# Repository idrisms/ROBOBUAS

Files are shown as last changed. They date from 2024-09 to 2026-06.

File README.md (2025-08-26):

## Demo Video untuk buyo menggunakan apps android

Tonton Video (https://youtube.com/shorts/SF0n9ZDPM6c?si=8_inQVv74NJLRzca)

ROBOBUAS

Bagai mana nak mula

1 - Muat turun semua kod dalam satu folder untuk sumo auto, untuk RC guna kod dalam MOTOR_ESP32HOTRC_V01
2 - Install Arduino software kalau belum (https://www.arduino.cc/en/software)
- 

3 - Install board manager ESP32 dari Espressif
Buka perisian arduino, kemudian tekan Board manager

Kemudian pilih kawasan carian dan cari esp32


4 - Lnstall CH341 untuk microcontroller esp32 kalau belum (https://www.wch-ic.com/downloads/CH341SER_ZIP.html)
- 

5- Extract dan click setup
- 

6 - Install CH341SER dengan menekan butang "INSTALL"
- 

7 - Bagaimana nak muat naik code. Tekan >> Tools >> Esp32 >> ESP32-WROOM-DA Module
7 - Bagaimana nak muat naik code. Tekan >> Tools >> Board >> ESP32-WROOM-DA Module
- 

8 - Sambungkan arduino anda dan pilih port yang telah aktif. Akan ade bunyi sesuatu di PC/Laptop anda sekiranya ESp32-30 di pasangkan sudah di kesan. Tekan Tools >> PORT >> Nombor port anda


9 - pastikan pilihan board dan port ayng betul
- 

10 - Waktu Muat Naik code di dalam ESP32,kadang-kadang perlu tekan butang Boot pada ESP32 waktu connecting keluar titik-titik......
- 
- 

**Untuk RC**
- Download MOTOR_ESP32HOTRC_V01 dan upload ke dalam robobuas esp32 board 
- Ikut seperti pendawaian di dalam https://sites.google.com/view/robobuasbuyov1
- JIka Board anda bukan ROBOBUAS BUYO, sila tukar nombor bin dalam kod berdasarkan nombor pin anda.
- 

- Hidupkan RC controller
- "BIND" receiver dengan transmitter bergantung kepada jenis RC controller anda
- Hidupkan Robot setelah semua pendawaian telah di semak. sebarang kerosakan board tidak ditanggung sekiranya semakan tidak di buat terlebih dahulu.**Pastikan RCcontroller tidak ditekan**
- Robot akan bergerak sendiri di awal suis dihidupkan selama beberapa saat namun ia akan berhenti sendiri sekiranyaia telah tersambung ke RC Controller
- Biasanya lampu receiver akan menyala tanpa berkelip sekiranya telah bersambung dengan RC controller
- Jika robot telah tersambung kepada controller, tetapi masih ada bunyi atau pergerakan yang perlahan, tinggikan nilai "OFFSET" secara gandaan 10 dan muat naik kod yang telah diubah
- 

- **AMARAN- Sila cabut ESP32 daripada ROBOBUAS untuk muat naikkod kerana board akan menyalurkan kuasa dari kabel USB ke Motor dan boleh merosakkan PC/LAPTOP sekiranya dibiarkan untuk tempoh yang lama**
- Tambah nilai offset sehinga tiada pergerakan walaupun RC controller tidak ditekan
- Sekirannya gerakan terbalik,tukar wayar dc motor kepada wayar pasangannya
- Sekiranya semua langkah-langkah ini diikuti dengan teliti, InsyaALLAH robot akan berfungsi

**UNtuk Auto**
- Buka SUMOROBOTAUTO_ROBOBUAS.ino menggunakan perisian ARDUINO
- Cara-cara ubah tetapan ada di dalam itu.

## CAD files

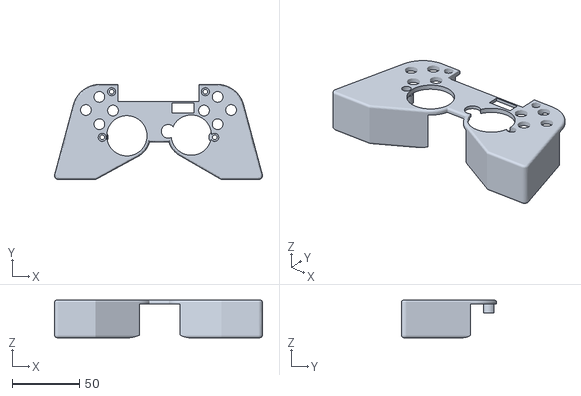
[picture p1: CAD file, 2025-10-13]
BEDIK/topcover_bedik.stl
155.0 x 70.9 x 28.0

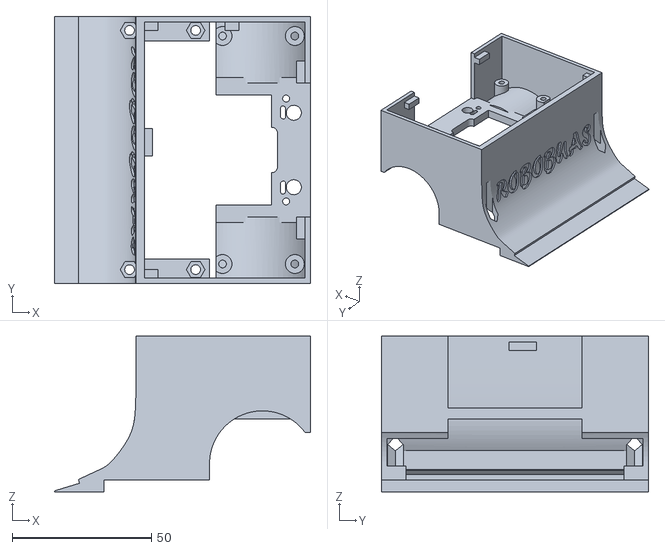
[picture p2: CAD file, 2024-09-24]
STL500RC/frontv2.stl
92.1 x 96.0 x 56.0

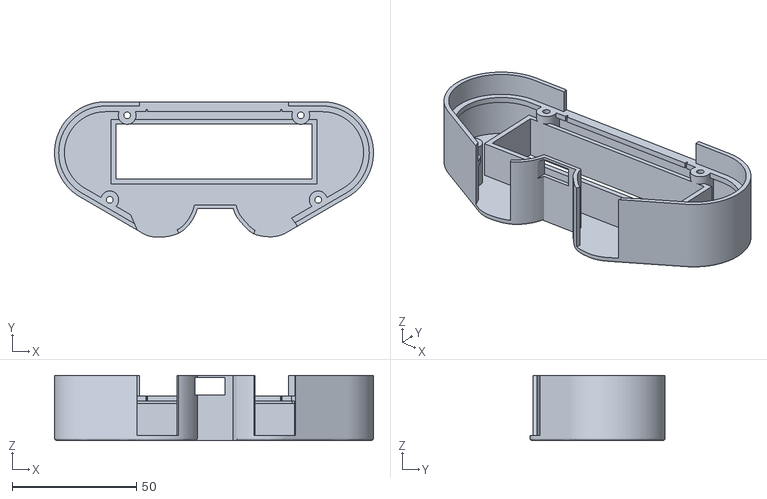
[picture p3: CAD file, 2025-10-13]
BEDIK/botcov_bedik.stl
128.4 x 54.5 x 26.2

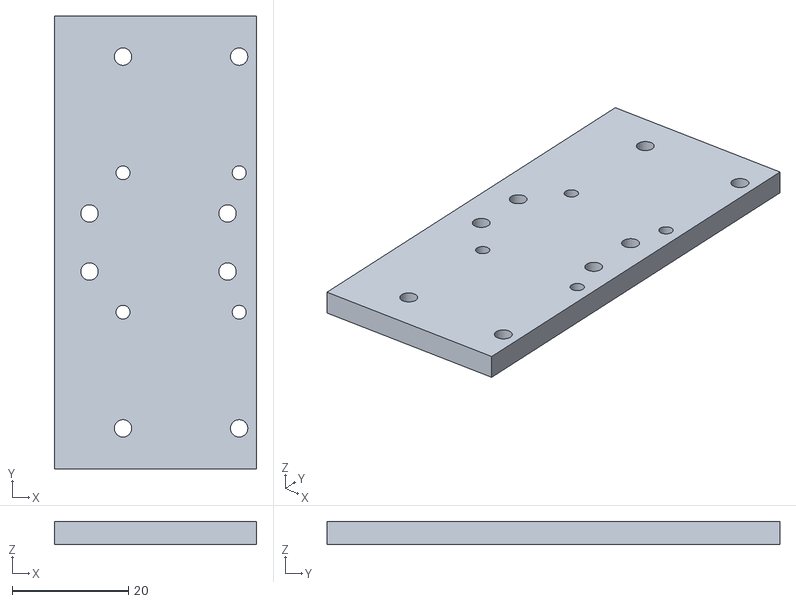
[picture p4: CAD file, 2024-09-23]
STL500RC/weigher.stl
34.8 x 78.0 x 4.00

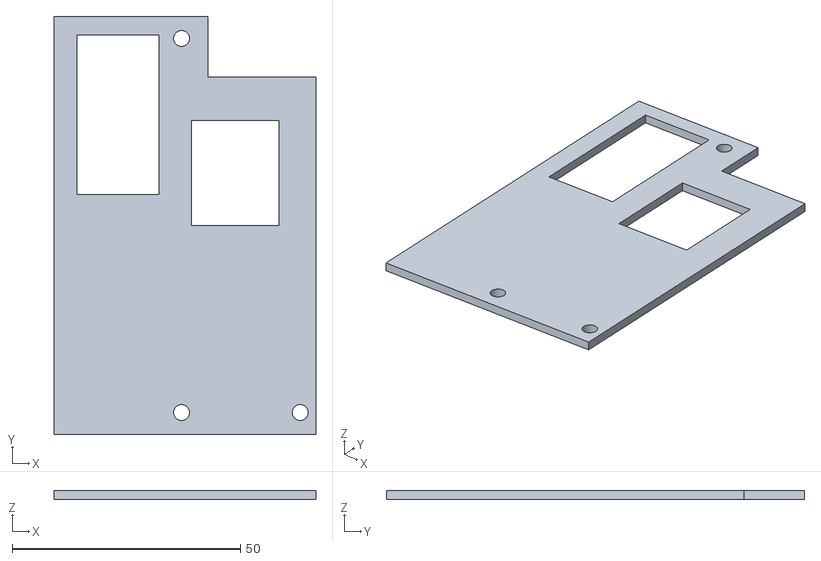
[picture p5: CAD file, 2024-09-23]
STL500RC/cover.stl
57.4 x 91.6 x 2.00

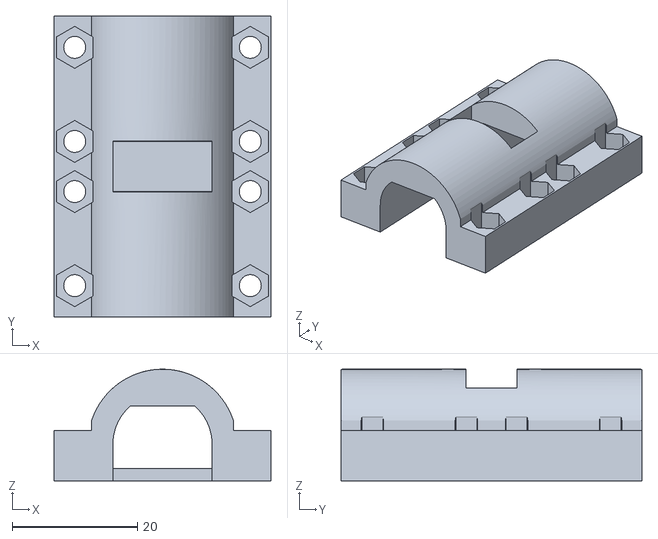
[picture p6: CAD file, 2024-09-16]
STL500RC/motorholder.stl
34.6 x 48.0 x 17.8

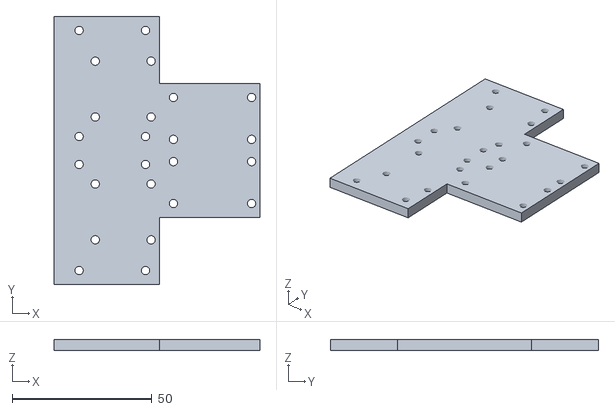
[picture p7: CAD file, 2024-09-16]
STL500RC/base.stl
73.8 x 96.0 x 4.00

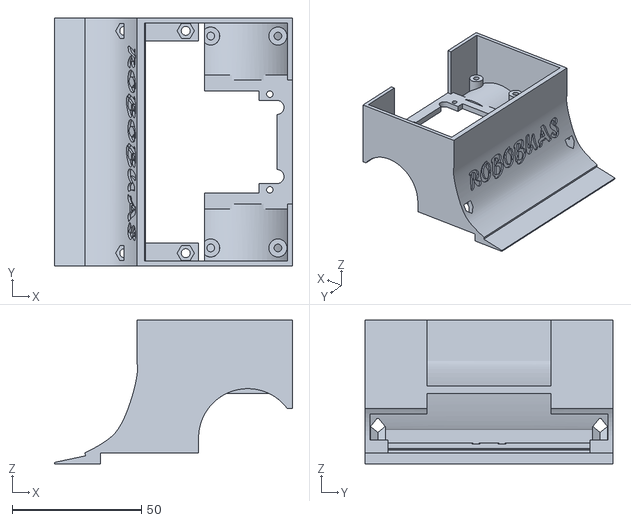
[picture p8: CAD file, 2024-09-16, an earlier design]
STL500RC/front(old).stl
92.1 x 96.0 x 55.6

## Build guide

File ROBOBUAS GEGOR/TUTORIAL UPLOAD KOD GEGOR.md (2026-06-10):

ROBOBUAS GEGOR

Bagai mana nak mula

1 - Muat turun kod RC_GEGOR_V1_0_FULL_VOLTAGE_LOCK.ino https://github.com/idrisms/ROBOBUAS/blob/main/ROBOBUAS%20GEGOR/RC_GEGOR_V1_0_FULL_VOLTAGE_LOCK.ino

2 - Install Arduino software kalau belum (https://www.arduino.cc/en/software)
- 

3 - Install board manager ESP32 dari Espressif
Buka perisian arduino, kemudian tekan Board manager

Kemudian pilih kawasan carian dan cari esp32


4 - Lnstall CH341 untuk microcontroller esp32 kalau belum (https://www.wch-ic.com/downloads/CH341SER_ZIP.html)
- 

5- Extract dan click setup
- 

6 - Install CH341SER dengan menekan butang "INSTALL"
- 

7 - Bagaimana nak muat naik code. Tekan >> Tools >> Esp32 >> ESP32-WROOM-DA Module
 
- 

8 - Sambungkan arduino anda dan pilih port yang telah aktif. Akan ade bunyi sesuatu di PC/Laptop anda sekiranya ESp32-30 di pasangkan sudah di kesan. Tekan Tools >> PORT >> Nombor port anda


9 - pastikan pilihan board dan port yang betul
- 

10 - Jika nak gunakan battery lipo 2s atau tak mahunguna safety battery, sila tukar nilai VMIN = 9.9 kepada 6.6 untuk lipo 2s (7.4V) atau kepada 0.0 jika anda tak mau safety pada battery

11-Contoh cara nak install library. Tekan icon library, cari neopixel dan install library Neopixel yang dibulatkan.
579013854-72b96216-1686-4d35-9036-d260c8034658



12 - Install Semua library yang diperlukan







13 - Waktu Muat Naik code di dalam ESP32,kadang-kadang perlu tekan butang Boot pada ESP32 waktu connecting keluar titik-titik......
- 
- 

**Untuk RC**

- Hidupkan RC controller
- "BIND" receiver dengan transmitter bergantung kepada jenis RC controller anda
- Hidupkan Robot setelah semua pendawaian telah di semak. sebarang kerosakan board tidak ditanggung sekiranya semakan tidak di buat terlebih dahulu.**Pastikan RCcontroller tidak ditekan**
- Biasanya lampu receiver akan menyala tanpa berkelip sekiranya telah bersambung dengan RC controller
- Jika robot telah tersambung kepada controller, tetapi masih ada bunyi atau pergerakan yang perlahan, ejas setting dekat remote
- Sekiranya gerakan terbalik,tukar wayar dc motor kepada wayar pasangannya
- Sekiranya semua langkah-langkah ini diikuti dengan teliti, InsyaALLAH robot akan berfungsi

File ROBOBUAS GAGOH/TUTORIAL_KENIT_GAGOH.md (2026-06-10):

1 - Muat turun code kenit/gagoh

2 - Install Arduino software kalau belum (https://www.arduino.cc/en/software)
- 

3 - Install board manager RPI dan tambah link ini (  https://github.com/earlephilhower/arduino-pico/releases/download/4.0.2/package_rp2040_index.json  ) dalam FILE->preferences
  

4 - Buka perisian arduino, kemudian tekan Board manager
  
  
5 - Kemudian pilih kawasan carian dan cari pico dan pilih seperti anak panah dan click install
  

6 - Sambung pendawaian seperti dalam https://sites.google.com/view/robobuasbuyopage/kenit

7 - Bagaimana nak muat naik code. Tekan >> Tools >> Board >> Raspberry Pi Pico >> Zero


8 - Install library Adafruit Neopixel jika guna code untuk Gagoh. Tekan icon library, cari neopixel dan install library enopixel yang dibulatkan
579013854-72b96216-1686-4d35-9036-d260c8034658

9 - Pilih port setelah di laptop/pc kenalpasti board dan muat naik seperti biasa

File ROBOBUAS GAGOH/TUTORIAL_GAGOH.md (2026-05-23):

1 - Muat turun code RC GAGGOH V2.2 (RC_GAGGOH_V2_2neo.ino untuk yang ada battery 12V safety-below 10V), (RC_GAGGOH_V2_2neo_noSafetyBat.ino untuk yang takde safety battery)

2 - Install Arduino software kalau belum (https://www.arduino.cc/en/software)
- 

3 - Install board manager RPI dan tambah link ini (  https://github.com/earlephilhower/arduino-pico/releases/download/4.0.2/package_rp2040_index.json  ) dalam FILE->preferences
  

4 - Buka perisian arduino, kemudian tekan Board manager
  
  
5 - Kemudian pilih kawasan carian dan cari pico dan pilih seperti anak panah dan click install
  

6 - Sambung pendawaian seperti dalam https://sites.google.com/view/robobuasbuyopage/kenit

7 - Bagaimana nak muat naik code. Tekan >> Tools >> Board >> Raspberry Pi Pico >> Zero


8 - Install library Adafruit Neopixel jika guna code untuk Gagoh. Tekan icon libreary, cari neopixel dan install library neopixel yang dibulatkan
579013854-72b96216-1686-4d35-9036-d260c8034658

9 - Pilih port setelah di laptop/pc kenalpasti board dan muat naik seperti biasa

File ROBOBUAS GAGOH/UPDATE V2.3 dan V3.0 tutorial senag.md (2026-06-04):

## Video Tutorial

Klik gambar di bawah untuk tonton video:

Tonton Video (https://youtube.com/shorts/C461Je05Bqs?si=8az38_ArpD2pnaIS)

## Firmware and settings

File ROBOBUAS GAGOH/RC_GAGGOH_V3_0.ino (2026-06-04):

/*
  =====================================================
  ROBOBUAS RC GAGOH V3.0
  -----------------------------------------------------
  Function:
  - RC control using CH1 and CH2
  - NeoPixel status LED
  - Forward and backward compensation using trimmer
  - Battery voltage check ONLY when robot is STOP
  - Low battery lock if Vbat <= Vmin
  - After lock, voltage can be checked again ONLY when STOP
  =====================================================
*/

#include <Adafruit_NeoPixel.h>

// ================= NEOPIXEL SETUP =================
#define PINSA 16
#define NUMPIXELS 1
Adafruit_NeoPixel pixels(NUMPIXELS, PINSA, NEO_GRB + NEO_KHZ800);

// ================= RC RECEIVER PIN =================
const int chA = 14;   // CH1 steering
const int chB = 15;   // CH2 throttle

// ================= MOTOR DRIVER PIN =================
#define M1B_PIN 4
#define M1A_PIN 7
#define EN_PIN 8
#define M2A_PIN 5
#define M2B_PIN 6

// ================= ANALOG INPUT PIN =================
#define VBAT_PIN 29
#define TRIMMER_PIN_FW 28
#define TRIMMER_PIN_BW 27

// ================= RC VARIABLE =================
int ch1, ch2;
int ch1prev = 1500;
int ch2prev = 1500;

int ch1Min = 1000;
int ch1Max = 2000;
int ch2Min = 1050;
int ch2Max = 1950;

int offset = 40;

// ================= BATTERY SETTING =================
float Vbat = 0;
const float pekali = 0.02992;

// Vmin = bilangan cell x 3.3V
// 2S LiPo = 6.6V
// 3S LiPo = 9.9V
// 4S LiPo = 13.2V
const float Vmin = 9.9;

// Unlock semula bila voltage naik lebih daripada Vmin + margin
const float recoveryMargin = 0.3;
const float maxBias =100;

bool lowBatteryLock = false;

// ================= COMPENSATION VARIABLE =================
int compensateRightFW = 0;
int compensateLeftFW = 0;
int compensateRightBW = 0;
int compensateLeftBW = 0;

// ================= LOW BATTERY BLINK =================
bool lowBatteryBlink = false;
unsigned long lastLowBatteryBlink = 0;
const unsigned long lowBatteryBlinkInterval = 200;

// ================= STOP MOTOR =================
void stopMotor() {
  analogWrite(M1A_PIN, 0);
  analogWrite(M1B_PIN, 0);
  analogWrite(M2A_PIN, 0);
  analogWrite(M2B_PIN, 0);
}

// ================= DRIVE MOTOR =================
// Semua arahan motor akan lalu function ini.
// Jika lowBatteryLock aktif, motor terus dipaksa STOP.
void driveMotor(int leftPWM, int rightPWM) {
  if (lowBatteryLock) {
    stopMotor();
    return;
  }

  leftPWM = constrain(leftPWM, -255, 255);
  rightPWM = constrain(rightPWM, -255, 255);

  // Left motor direction
  if (leftPWM > 0) {
    analogWrite(M1A_PIN, leftPWM);
    analogWrite(M1B_PIN, 0);
  } else if (leftPWM < 0) {
    analogWrite(M1A_PIN, 0);
    analogWrite(M1B_PIN, abs(leftPWM));
  } else {
    analogWrite(M1A_PIN, 0);
    analogWrite(M1B_PIN, 0);
  }

  // Right motor direction
  if (rightPWM > 0) {
    analogWrite(M2A_PIN, rightPWM);
    analogWrite(M2B_PIN, 0);
  } else if (rightPWM < 0) {
    analogWrite(M2A_PIN, 0);
    analogWrite(M2B_PIN, abs(rightPWM));
  } else {
    analogWrite(M2A_PIN, 0);
    analogWrite(M2B_PIN, 0);
  }
}

// ================= LOW BATTERY LED =================
void lowBatteryStop() {
  stopMotor();

  unsigned long now = millis();

  if (now - lastLowBatteryBlink >= lowBatteryBlinkInterval) {
    lowBatteryBlink = !lowBatteryBlink;
    lastLowBatteryBlink = now;
  }

  if (lowBatteryBlink) {
    pixels.setPixelColor(0, pixels.Color(80, 20, 0));  // orange blink
  } else {
    pixels.setPixelColor(0, pixels.Color(0, 0, 0));
  }

  pixels.show();
}

// ================= READ FORWARD TRIMMER =================
void readTrimmerFW() {
  int trimValueFW = analogRead(TRIMMER_PIN_FW);

  if (trimValueFW < 512) {
    compensateLeftFW = map(512 - trimValueFW, 0, 512, 0, maxBias);
    compensateRightFW = 0;
  } else {
    compensateRightFW = map(trimValueFW - 512, 0, 511, 0, maxBias);
    compensateLeftFW = 0;
  }
}

// ================= READ BACKWARD TRIMMER =================
void readTrimmerBW() {
  int trimValueBW = analogRead(TRIMMER_PIN_BW);

  if (trimValueBW < 512) {
    compensateLeftBW = map(512 - trimValueBW, 0, 512, 0, maxBias);
    compensateRightBW = 0;
  } else {
    compensateRightBW = map(trimValueBW - 512, 0, 511, 0, maxBias);
    compensateLeftBW = 0;
  }
}

// Negative value means compensation to left side.
// Positive value means compensation to right side.
int getCompFWDisplay() {
  if (compensateLeftFW > 0) return -compensateLeftFW;
  return compensateRightFW;
}

int getCompBWDisplay() {
  if (compensateLeftBW > 0) return -compensateLeftBW;
  return compensateRightBW;
}

void setup() {
  Serial.begin(115200);

  pinMode(chA, INPUT);
  pinMode(chB, INPUT);

  pinMode(M1A_PIN, OUTPUT);
  pinMode(M1B_PIN, OUTPUT);
  pinMode(M2A_PIN, OUTPUT);
  pinMode(M2B_PIN, OUTPUT);
  pinMode(EN_PIN, OUTPUT);

  digitalWrite(EN_PIN, HIGH);
  stopMotor();

  pixels.begin();

  // Startup LED test
  pixels.setPixelColor(0, pixels.Color(20, 0, 0));
  pixels.show();
  delay(300);

  pixels.setPixelColor(0, pixels.Color(0, 20, 0));
  pixels.show();
  delay(300);

  pixels.setPixelColor(0, pixels.Color(0, 0, 20));
  pixels.show();
  delay(300);

  pixels.clear();
  pixels.show();

  delay(500);
}

void loop() {
  // Read compensation trimmer
  readTrimmerFW();
  readTrimmerBW();

  // Read RC signal
  ch1 = pulseIn(chA, HIGH, 30000);
  delay(1);

  ch2 = pulseIn(chB, HIGH, 30000);
  delay(1);

  // If signal lost, use previous value
  if (ch1 < 700) ch1 = ch1prev;
  else ch1 = constrain(ch1, ch1Min, ch1Max);

  if (ch2 < 700) ch2 = ch2prev;
  else ch2 = constrain(ch2, ch2Min, ch2Max);

  ch1prev = ch1;
  ch2prev = ch2;

  // Convert RC signal to PWM value
  int SpeedCh1 = map(ch1, ch1Min, ch1Max, -255, 255);
  int SpeedCh2 = map(ch2, ch2Min, ch2Max, -255, 255);

  int forward = SpeedCh2;
  int turn = SpeedCh1;

  bool belowOffset = abs(forward) < offset && abs(turn) < offset;

  // Serial monitor display
  Serial.print("CH1:");
  Serial.print(ch1);
  Serial.print(" | CH2:");
  Serial.print(ch2);
  Serial.print(" | SPD1:");
  Serial.print(SpeedCh1);
  Serial.print(" | SPD2:");
  Serial.print(SpeedCh2);
  Serial.print(" | VBAT:");
  Serial.print(Vbat);
  Serial.print(" | LOCK:");
  Serial.print(lowBatteryLock);
  Serial.print(" | CompFW:");
  Serial.print(getCompFWDisplay());
  Serial.print(" | CompBW:");
  Serial.print(getCompBWDisplay());

  if (belowOffset) {
    Serial.print(" | Motion:STOP");
  } else if (lowBatteryLock) {
    Serial.print(" | Motion:LOW BAT");
  } else if (abs(forward) >= abs(turn)) {
    if (forward > 0) Serial.print(" | Motion:FW");
    else Serial.print(" | Motion:BW");
  } else {
    if (turn > 0) Serial.print(" | Motion:RIGHT");
    else Serial.print(" | Motion:LEFT");
  }

  // Voltage check hanya waktu STOP
  if (belowOffset) {
    stopMotor();

    Vbat = analogRead(VBAT_PIN) * pekali;

    if (Vbat <= Vmin) {
      lowBatteryLock = true;
    }

    if (lowBatteryLock && Vbat > (Vmin + recoveryMargin)) {
      lowBatteryLock = false;
    }

    if (lowBatteryLock) {
      lowBatteryStop();
      Serial.println(" | LOW BATTERY LOCK");
    } else {
      pixels.setPixelColor(0, pixels.Color(0, 30, 0));
      pixels.show();
      Serial.println(" | STOP / BATTERY OK");
    }

    delay(15);
    return;
  }

  // Kalau battery lock, motor tidak dibenarkan bergerak
  if (lowBatteryLock) {
    lowBatteryStop();
    Serial.println(" | LOW BATTERY MOTOR BLOCKED");
    delay(15);
    return;
  }

  // Normal movement LED
  if (forward > 0) {
    pixels.setPixelColor(0, pixels.Color(0, 0, 30));
  } else {
    pixels.setPixelColor(0, pixels.Color(30, 0, 0));
  }

  pixels.show();

  // Mixing control
  int leftPWM = forward + turn;
  int rightPWM = forward - turn;

  leftPWM = constrain(leftPWM, -255, 255);
  rightPWM = constrain(rightPWM, -255, 255);

  // Forward compensation
  if (leftPWM > 0) {
    leftPWM -= compensateLeftFW * abs(leftPWM) / 255;
  }

  if (rightPWM > 0) {
    rightPWM -= compensateRightFW * abs(rightPWM) / 255;
  }

  // Backward compensation
  if (leftPWM < 0) {
    leftPWM += compensateLeftBW * abs(leftPWM) / 255;
  }

  if (rightPWM < 0) {
    rightPWM += compensateRightBW * abs(rightPWM) / 255;
  }

  leftPWM = constrain(leftPWM, -255, 255);
  rightPWM = constrain(rightPWM, -255, 255);

  Serial.print(" | LEFT:");
  Serial.print(leftPWM);
  Serial.print(" | RIGHT:");
  Serial.println(rightPWM);

  driveMotor(leftPWM, rightPWM);

  delay(15);
}

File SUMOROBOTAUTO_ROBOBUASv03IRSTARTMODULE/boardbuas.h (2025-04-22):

#ifndef BOARDBUAS_H
#define BOARDBUAS_H

// Define the board version to be used (uncomment one line to select)
//#define BUYOV1
//#define HOGOHV1
#define BOLOHV2RC


#ifdef BOLOHV2RC
#define SENSOP_KANAN 39
#define SENSOP_KANANTENGAH 34
#define SENSOP_TENGAH 35
#define SENSOP_KIRITENGAH 32   // SUMO AUTO uses 5 sensors, Analog
#define SENSOP_KIRI 33          // SENSOP = SENSOR opponent
#define SENSOR_LANTAI_KANAN 36  // EDGE SENSOR
#define SENSOR_LANTAI_KIRI 25
#define PIN_MULA1 26
#define chA 13
#define chB 14
#define suisinverse 0
#define IRSTART_MODULE 27
//#define PIN_MULA2 17
//#define PIN_MULA3 16
//#define PIN_MULA4 4
#define MOTOR_A_RPWM 21  // motor kanan
#define MOTOR_A_LPWM 22
#define MOTOR_B_RPWM 16  // motor kiri
#define MOTOR_B_LPWM 4
#define LED_BUILTIN 2  // for ersp32

#elif defined(BUYOV1)
#define SENSOP_KANAN 27
#define SENSOP_KANANTENGAH 26
#define SENSOP_TENGAH 14
#define SENSOP_KIRITENGAH 12    // SUMO AUTO uses 5 sensors, Analog
#define SENSOP_KIRI 13          // SENSOP = SENSOR opponent
#define SENSOR_LANTAI_KANAN 33  // EDGE SENSOR
#define SENSOR_LANTAI_KIRI 32
#define PIN_MULA1 34
#define chA 13
#define chB 14
#define suisinverse 1
//#define PIN_MULA2 17
//#define PIN_MULA3 16
//#define PIN_MULA4 4
#define MOTOR_A_RPWM 19  // motor kanan
#define MOTOR_A_LPWM 18
#define MOTOR_B_RPWM 17  // motor kiri
#define MOTOR_B_LPWM 16
#define LED_BUILTIN 2  // for ersp32

#elif defined(HOGOHV1)
#define SENSOP_KANAN 39
#define SENSOP_KANANTENGAH 34
#define SENSOP_TENGAH 35
#define SENSOP_KIRITENGAH 32    // SUMO AUTO uses 5 sensors, Analog
#define SENSOP_KIRI 33          // SENSOP = SENSOR opponent
#define SENSOR_LANTAI_KANAN 36  // EDGE SENSOR
#define SENSOR_LANTAI_KIRI 25
#define PIN_MULA1 26
#define chA 13
#define chB 14
#define IRSTART_MODULE 27
#define suisinverse 0
//#define PIN_MULA2 17
//#define PIN_MULA3 16
//#define PIN_MULA4 4
#define MOTOR_A_RPWM 19  // motor kanan
#define MOTOR_A_LPWM 23

#define MOTOR_B_RPWM 17  // motor kiri
#define MOTOR_B_LPWM 18
#define LED_BUILTIN 2  // for ersp32

#else
#error "No valid board selected. Please uncomment one board definition."
#endif

#endif  // BOARDBUAS_H

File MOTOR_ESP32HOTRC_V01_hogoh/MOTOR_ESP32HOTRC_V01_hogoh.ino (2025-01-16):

const int chA = 13;  //on ESP channel 1 dari controller anda//
// cara sambungan, V dari ESP (5V)- Barismerah ke V dari Reciever
// cara sambungan, G dari ESP ke G dari Reciever
// cara sambungan, Pin 13 dari ESP sambung ke S receiver (yang mula-mula sekali)
const int chB = 14;  ///on ESP
// #define RPWM1_PIN 23  //ESP32 WROOM //ROBOBUAS BUYO V0
// #define LPWM1_PIN 22
// #define RPWM2_PIN 19
// #define LPWM2_PIN 21

#define RPWM1_PIN 23  //ESP32 WROOM //ROBOBUAS BUYO Vhogoh v1.0
#define LPWM1_PIN 19
#define RPWM2_PIN 18
#define LPWM2_PIN 17

int ch1;  //Variables to store and display the values of each channel
int ch2;  //Variables to store and display the values of each channel

int ch1Min = 1000;  // read from serial monitor
int ch1Max = 2000;  // read from serial monitor
int ch2Min = 1000;  // read from serial monitorQ
int ch2Max = 2000;  // read from serial monitor

int offset = 40;  // Offset value for STOP function, get value from Serial Monitor
int val;

void setup() {

  //
  Serial.begin(9600);
  pinMode(chA, INPUT);
  pinMode(chB, INPUT);
  pinMode(LPWM1_PIN, OUTPUT);
  pinMode(RPWM1_PIN, OUTPUT);
  pinMode(LPWM2_PIN, OUTPUT);
  pinMode(RPWM2_PIN, OUTPUT);
  analogWrite(LPWM1_PIN, 0);
  analogWrite(RPWM1_PIN, 0);
  analogWrite(LPWM2_PIN, 0);
  analogWrite(RPWM2_PIN, 0);
}

void loop() {
  // put your main code here, to run repeatedly:
  // read the input channels
  ch1 = pulseIn(chA, HIGH);  //Read and store channel 1
                             // ch1 = constrain(ch1, 1000, 2000);
  Serial.print("Ch1:");      //Display text string on Serial Monitor to distinguish variables
  Serial.print(ch1);         //Print in the value of channel 1
  Serial.print("|");

  ch2 = pulseIn(chB, HIGH);
  // ch2 = constrain(ch2, 1000, 2000);
  Serial.print("Ch2:");
  Serial.print(ch2);
  Serial.print("|");

  //LEFT & RIGHT
  int SpeedCh1 = map(ch1, ch1Min, ch1Max, -255, 255);
  Serial.print(SpeedCh1);
  Serial.print("|");

  //FORWARD & BACKWARD
  int SpeedCh2 = map(ch2, ch2Min, ch2Max, -255, 255);
  Serial.print(SpeedCh2);
  Serial.println("|");

  if (SpeedCh2 > offset && SpeedCh2 <= 255 && SpeedCh1 > 0) {
    Serial.print("FORWARD");
    Serial.print("|");
    analogWrite(RPWM1_PIN, 0);
    analogWrite(LPWM1_PIN, abs(SpeedCh2));
    analogWrite(RPWM2_PIN, 0);
    analogWrite(LPWM2_PIN, abs(SpeedCh2) - abs(SpeedCh1));
  }

  else if (SpeedCh2 > offset && SpeedCh2 <= 255 && SpeedCh1 <= 0) {
    Serial.print("FORWARD");
    Serial.print("|");
    analogWrite(RPWM1_PIN, 0);
    analogWrite(LPWM1_PIN, abs(SpeedCh2) - abs(SpeedCh1));
    analogWrite(RPWM2_PIN, 0);
    analogWrite(LPWM2_PIN, abs(SpeedCh2));
  }

  else if (SpeedCh2 < -offset && SpeedCh2 >= -255) {
    Serial.print("BACKWARD");
    Serial.print("|");
    analogWrite(RPWM1_PIN, abs(SpeedCh2));
    analogWrite(LPWM1_PIN, 0);
    analogWrite(RPWM2_PIN, abs(SpeedCh2));
    analogWrite(LPWM2_PIN, 0);
  }

  else if (SpeedCh1 > offset && SpeedCh1 <= 255) {
    Serial.print("Turn RIGHT");
    Serial.print("|");
    analogWrite(RPWM1_PIN, 0);
    analogWrite(LPWM1_PIN, abs(SpeedCh1));
    analogWrite(RPWM2_PIN, abs(SpeedCh1));
    analogWrite(LPWM2_PIN, 0);
  }

  else if (SpeedCh1 < -offset && SpeedCh1 >= -255) {
    Serial.print("Turn LEFT");
    Serial.print("|");
    analogWrite(RPWM1_PIN, abs(SpeedCh1));
    analogWrite(LPWM1_PIN, 0);
    analogWrite(RPWM2_PIN, 0);
    analogWrite(LPWM2_PIN, abs(SpeedCh1));
  }


  else if (SpeedCh1 <= offset && SpeedCh1 >= -offset) {
    Serial.print("STOP");
    Serial.print("|");
    // Move in reverse

    analogWrite(LPWM1_PIN, 0);
    analogWrite(RPWM1_PIN, 0);
    analogWrite(LPWM2_PIN, 0);
    analogWrite(RPWM2_PIN, 0);
  }

  delay(1);
}

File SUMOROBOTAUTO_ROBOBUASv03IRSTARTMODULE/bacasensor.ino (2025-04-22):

void bacaSensor() {
  if (sensorOppoLow == 1) {
    rightIR = analogRead(SENSOP_KANAN) / 4;
    midRight = analogRead(SENSOP_KANANTENGAH) / 4;    //
    middleIR = analogRead(SENSOP_TENGAH) / 4;         //
    leftIR = analogRead(SENSOP_KIRI) / 4;             //
    midLeft = analogRead(SENSOP_KIRITENGAH) / 4;      //
    rightEdge = analogRead(SENSOR_LANTAI_KANAN) / 4;  //
    leftEdge = analogRead(SENSOR_LANTAI_KIRI) / 4;    //
  } else {
    rightIR = 1023 - analogRead(SENSOP_KANAN) / 4;
    midRight = 1023 - analogRead(SENSOP_KANANTENGAH) / 4;  //
    middleIR = 1023 - analogRead(SENSOP_TENGAH) / 4;       //
    leftIR = 1023 - analogRead(SENSOP_KIRI) / 4;           //
    midLeft = 1023 - analogRead(SENSOP_KIRITENGAH) / 4;    //
    rightEdge = analogRead(SENSOR_LANTAI_KANAN) / 4;       //
    leftEdge = analogRead(SENSOR_LANTAI_KIRI) / 4;         //
  }

  if ((rightIR > thold_turn) || (middleIR < thold_obs) || (leftIR > thold_turn)) {
    detectOppo = 0;  // to reset whether opponnent is detected using any obstacle IR sensor
  }
  if (middleIR > thold_obs) {
    toHit = 1;
  }
  irStart = digitalRead(IRSTART_MODULE);
}

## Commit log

2024-09-16 stl file robobuas 500 RC
    [base.stl, front.stl, motorholder.stl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]
2024-09-17 Update MOTOR_ESP32HOTRC_V01.ino
    comment constrain due tuew jitter at the robot
    [MOTOR_ESP32HOTRC_V01.ino]
2024-09-17 Update MOTOR_ESP32HOTRC_V01.ino
    update offset to40, remove constrain due to jerking
2024-09-23 add new design for buyo, bilis and cover
    [cover.stl, frontBuyo.stl, frontbilis.stl]
2024-09-23 tambah front buyo, front bilis, cover dan weigher
    [weigher.stl]
2024-09-24 update design
    update design
    [base.stl, cover.stl, motorholder.stl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]
2024-09-24 Update 500g RC body ROBOBUAS
    [base.stl, cover.stl, front(old).stl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]
2025-01-12 Update MOTOR_ESP32HOTRC_V01_BILIS.ino
    remove jerking cause value from controller become negative
2025-01-16 Update MOTOR_ESP32HOTRC_V01_hogoh.ino
    RC untuk HOGOH
2025-02-19 Update MOTOR_ESP32HOTRC_V01_BILIS.ino
    update Pin number for board version 2
2025-04-22 SUMO ROBOT AUTO PIN 27 IR START MODULE
    FOR BOLOH HOGOH
2025-08-26 Add files via upload
    https://youtube.com/shorts/SF0n9ZDPM6c?si=8_inQVv74NJLRzca
    [ROBOBUAS_MOVE_ANDROIDV1.ino]
2025-10-13 Create file stl
2025-10-13 Upload file stl. Setting print guna BAMBULAB
    [botcov_bedik.stl, topcover_bedik.stl]
2025-11-13 Update RC_GAGGOH_V2_2neo.ino
    Code edit supaya robot tak bergetar. Check volt selepas robot berhenti sahaja. Sebelum ni cek voltage waktu robot bergerak dan disebabkan voltage drop, robot berhenti walau disuruh berjalan. Vibrate gitu
2026-02-16 pi driver shield for testing
